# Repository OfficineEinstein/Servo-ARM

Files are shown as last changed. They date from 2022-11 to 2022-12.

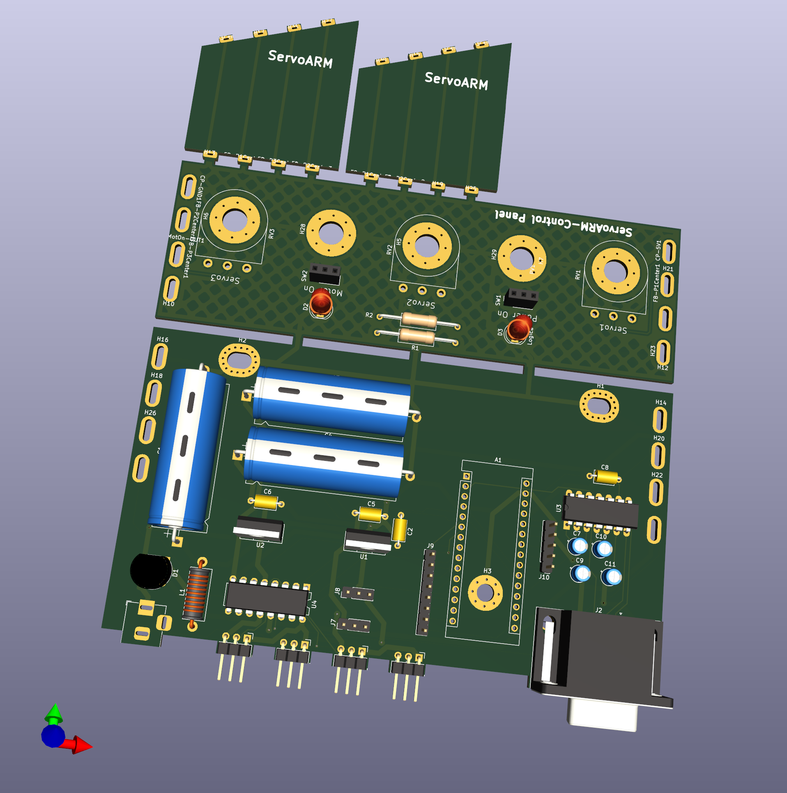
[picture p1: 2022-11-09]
ServoARM-r01/Kic/ServoARM-r01/ServoARM-r01.png

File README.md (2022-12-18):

# Servo-ARM
Tester Controller per servo analogici (Futaba)
## Descrizione di massima
Questo dispoositivo nasce per consentire l'agevole studio dei generatori PWM, delle loro funzionalità e del loro sfruttamento. Per praticità è stato individuato come controllore per servo meccanismi a tre fili di tipo Futaba ma, in effetti è utilizzabile per un'ampio spettro di esperienze che comprendono l'utilizzo di segnali PWM o comunque la generazione di onde quadre o treni di impulsi anche associati ad un'uscita di potenza.

Il dispositivo si basa su 
##### * un microcontrollore Atmel ATMEGA328P installato su una scheda Arduino Nano equivalente.
##### * tre potenziometri per la scelta dell'ampiezza dell'inpulso dei 3 generatori PWM.
##### * quattro uscite per servo controllate tramite quattro semi ponti H.
##### * un alimentatore con ingresso in corrente continua o alternata e due unità di uscita separate (logica e servo).
Il potenziometro numero 3 è collegato a due uscite così da poter controllare due servo in contemporanea.

# Hardware
## r00
La versione zero (quella di cui attualmente sono disponibili i PCB) presenta alcune criticità in fase di correzione nella versione r01

### Ponnte raddrizzatore
Il ponte previsto nel PCB ha una piedinatura inusuale per cui, se si usa un ponte standard si devono piegare ed incrociare i piedini in maniera da posizion arli correttamente

### Piedinatura di uscita
La piedinatura di uscita per i servo ha i piedini 2 e 3 invertiti (fa riferimento ad un tipo di servo diverso dallo standard Futaba)

## r01
Nella versione r01 attualmente in fase di perfezionamento tutti i problemi evidenziati nella versione r00 sono in fase di eliminazione. I PCB della versione saranno facilemente riconoscibili anche attraverso la dicitura PCB r01 riportata nelle serigrafie

# Software
Al momento non è stata rilasciata una versione di riferimento del codice per il funzionamento di questo strumento.

Si ricorda che se si adotta come microcontrollore la scheda Maker Nano, in fase di compilazione si dovrà scegliere la versione di bootloader più aggiornata diversamente verrà restituito un errore in fase di caricamento del codice.

Il dispositivo si basa sulla funzione PWM disponibile nella libreria di base di Arduino (analogWrite()).
Anche se in fase di sperimentazione è possibile utilizzare le librerie disponibili per il controllo dei servo, sarebbe opportuno controllare i generatori PWM direttamente ovvero tramite comandi analogWrite() e non tramite chiamate alle librerie per il controllo dei servo.

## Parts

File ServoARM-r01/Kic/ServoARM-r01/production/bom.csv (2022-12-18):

Designator | Footprint | Quantity | Value | LCSC Part #
A1 | Arduino_Nano | 1 | Arduino_Nano_v3.x
C1, C3, C4 | CP_Axial_L37.0mm_D13.0mm_P43.00mm_Horizontal | 3 | C_Polarized
C10, C11, C7, C9 | CP_Radial_D4.0mm_P2.00mm | 4 | 1uF
C2, C5, C6 | C_Axial_L5.1mm_D3.1mm_P7.50mm_Horizontal | 3 | C
C8 | C_Axial_L5.1mm_D3.1mm_P7.50mm_Horizontal | 1 | 100nF
CP-5V1, CP-GND1, FP-MotOn-OUT1, H10, H12, H14, H16, H18, H20, H21, H22, H23, H26 | Asola | 13 | MountingHole_Pad
D1 | Diode_Bridge_Round_D8.9mm | 1 | D_Bridge_+A-A
D2 | LED_D5.0mm | 1 | Motori
D3 | LED_D5.0mm | 1 | Logica
FB-P1Center1 | Asola | 1 | FB-P1Center
FB-P1Center2, FB-P1Center3 | TenonePerAsola | 2 | FB-P1Center
FB-P2Center1 | Asola | 1 | FB-P2Center
FB-P2Center2, FB-P2Center3 | TenonePerAsola | 2 | FB-P2Center
FB-P3Center1 | Asola | 1 | FB-P3Center
FB-P3Center3, FB-P3Center4, FB-P3Center5, FB-P3Center6 | TenonePerAsola | 4 | FB-P3Center
H1, H2 | MountingHole_4.3x6.2mm_M4_Pad_Via | 2 | MountingHole_Pad
H13, H15, H17, H19, H25, H27, H30, H31 | TenonePerAsola | 8 | MountingHole_Pad
H28, H29, H5, H6, H7 | MountingHole_6.5mm_Pad_Via | 5 | MountingHole_Pad
H3 | MountingHole_4.3mm_M4_Pad_Via | 1 | MountingHole_Pad
J1 | BarrelJack_Horizontal | 1 | Barrel_Jack_MountingPin
J10 | PinHeader_1x05_P2.54mm_Vertical | 1 | Conn_01x05
J2 | DSUB-9_Female_Horizontal_P2.77x2.84mm_EdgePinOffset14.56mm_Housed_MountingHolesOffset15.98mm | 1 | DB9_Female_MountingHoles
J3, J4, J5, J6 | PinHeader_1x03_P2.54mm_Horizontal | 4 | Conn_01x03
J7, J8 | PinHeader_1x03_P2.54mm_Vertical | 2 | Conn_01x03
J9 | PinHeader_1x08_P2.54mm_Vertical | 1 | Conn_01x08
L1 | L_Axial_L12.0mm_D5.0mm_P15.24mm_Horizontal_Fastron_MISC | 1 | L
R1, R2 | R_Axial_DIN0309_L9.0mm_D3.2mm_P20.32mm_Horizontal | 2 | R
RV1, RV2, RV3 | Potentiometer_Omeg_PC16BU_Vertical | 3 | R_Potentiometer
SW1 | PinSocket_1x03_P2.54mm_Vertical | 1 | SwGenerale
SW2 | PinSocket_1x03_P2.54mm_Vertical | 1 | SwMotori
U1, U2 | TO-220-3_Vertical | 2 | LM7805_TO220
U3 | DIP-14_W7.62mm_LongPads | 1 | MAX232
U4 | DIP-16_W7.62mm | 1 | SN754410NE

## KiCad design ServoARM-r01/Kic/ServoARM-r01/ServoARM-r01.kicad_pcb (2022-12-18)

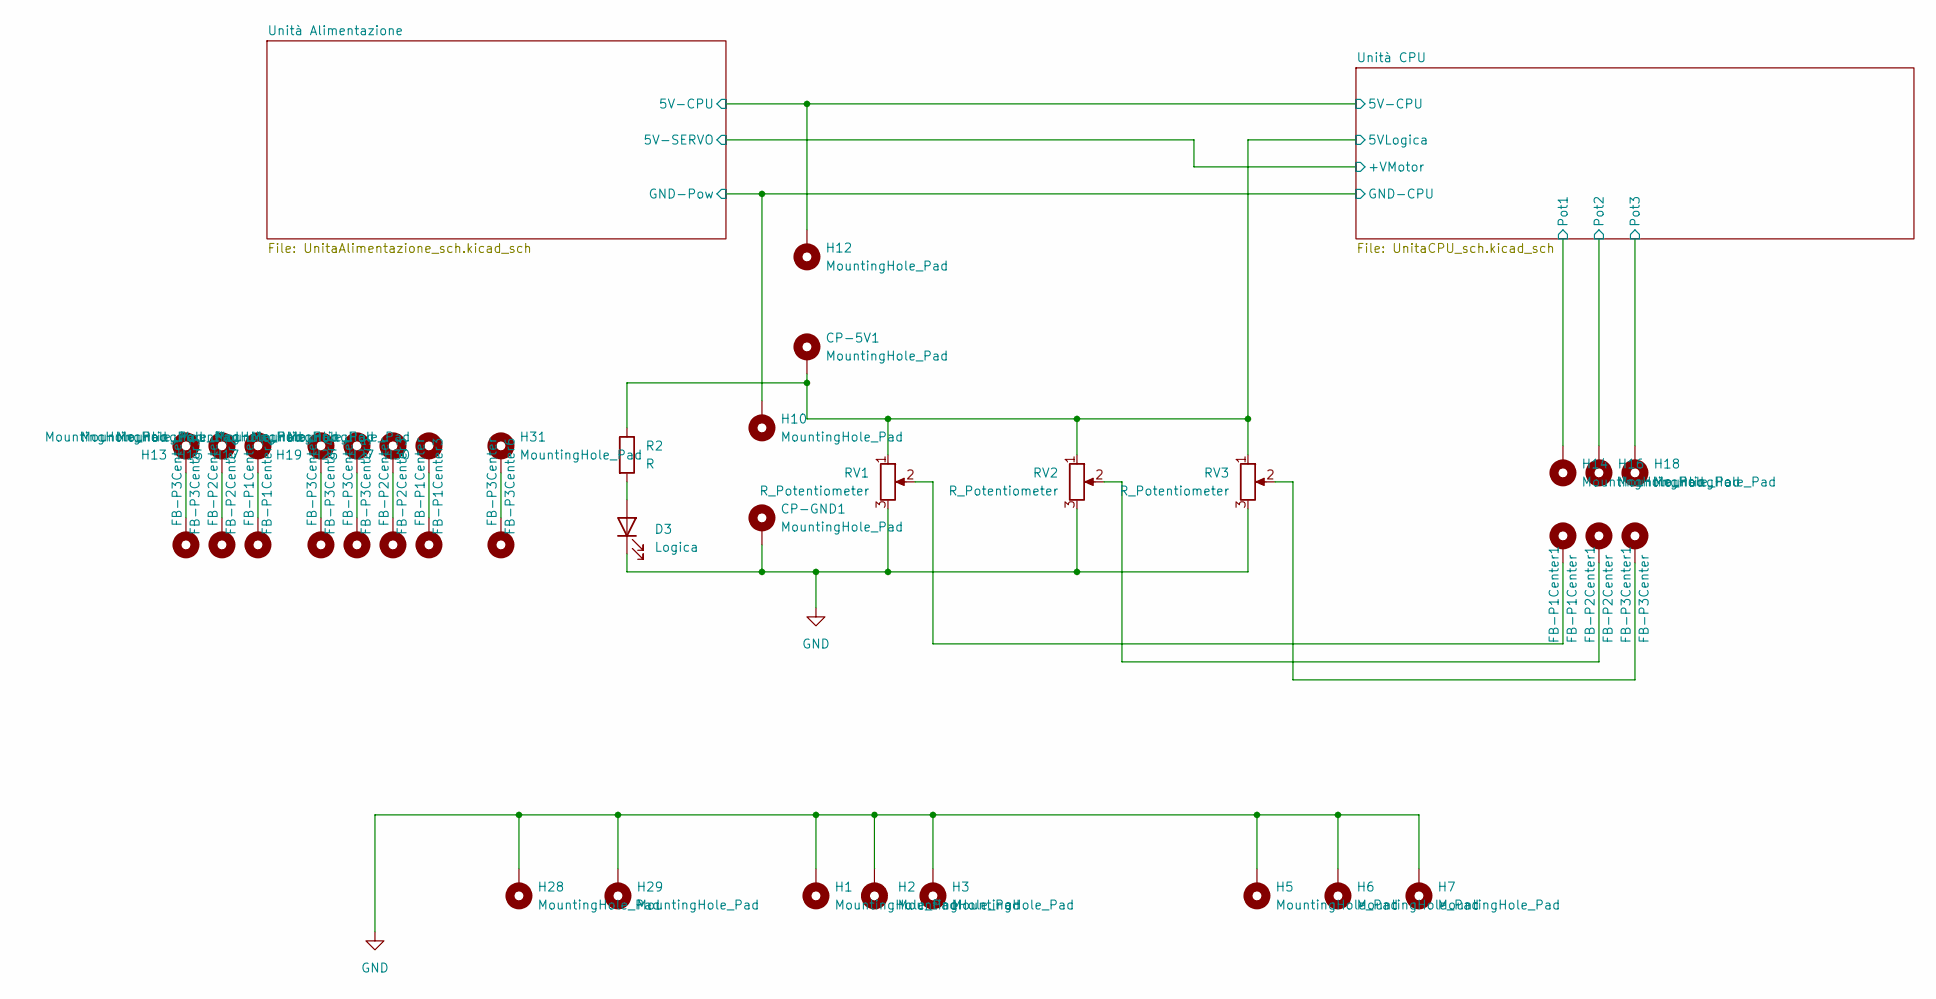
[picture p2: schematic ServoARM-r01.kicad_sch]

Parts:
CP-5V1: MountingHole_Pad; Asola
CP-GND1: MountingHole_Pad; Asola
D3: Logica; LED_D5.0mm
FB-P1Center1: FB-P1Center; Asola
FB-P1Center2, FB-P1Center3: FB-P1Center; TenonePerAsola
FB-P2Center1: FB-P2Center; Asola
FB-P2Center2, FB-P2Center3: FB-P2Center; TenonePerAsola
FB-P3Center1: FB-P3Center; Asola
FB-P3Center3, FB-P3Center4, FB-P3Center5, FB-P3Center6: FB-P3Center; TenonePerAsola
H1, H2: MountingHole_Pad; MountingHole_4.3x6.2mm_M4_Pad_Via
H3: MountingHole_Pad; MountingHole_4.3mm_M4_Pad_Via
H5, H6, H7, H28, H29: MountingHole_Pad; MountingHole_6.5mm_Pad_Via
H10, H12, H14, H16, H18: MountingHole_Pad; Asola
H13, H15, H17, H19, H25, H27, H30, H31: MountingHole_Pad; TenonePerAsola
R2: R; R_Axial_DIN0309_L9.0mm_D3.2mm_P20.32mm_Horizontal
RV1, RV2, RV3: R_Potentiometer; Potentiometer_Omeg_PC16BU_Vertical

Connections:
/Unità CPU/5VLogica: CP-5V1.1, R2.1, RV1.1, RV2.1, RV3.1; also elsewhere on the board
/Unità CPU/Pot1: H14.1; also elsewhere on the board
/Unità CPU/Pot2: H16.1; also elsewhere on the board
/Unità CPU/Pot3: H18.1; also elsewhere on the board
GND: CP-GND1.1, D3.1 (K), H1.1, H2.1, H3.1, H5.1, H6.1, H7.1, H10.1, H28.1, H29.1, RV1.3, RV2.3, RV3.3; also elsewhere on the board
unnamed: D3.2 (A), R2.2
unnamed: FB-P1Center1.1, RV1.2
unnamed: FB-P1Center2.1, H17.1
unnamed: FB-P1Center3.1, H30.1
unnamed: FB-P2Center1.1, RV2.2
unnamed: FB-P2Center2.1, H15.1
unnamed: FB-P2Center3.1, H27.1
unnamed: FB-P3Center1.1, RV3.2
unnamed: FB-P3Center3.1, H13.1
unnamed: FB-P3Center4.1, H19.1
unnamed: FB-P3Center5.1, H25.1
unnamed: FB-P3Center6.1, H31.1

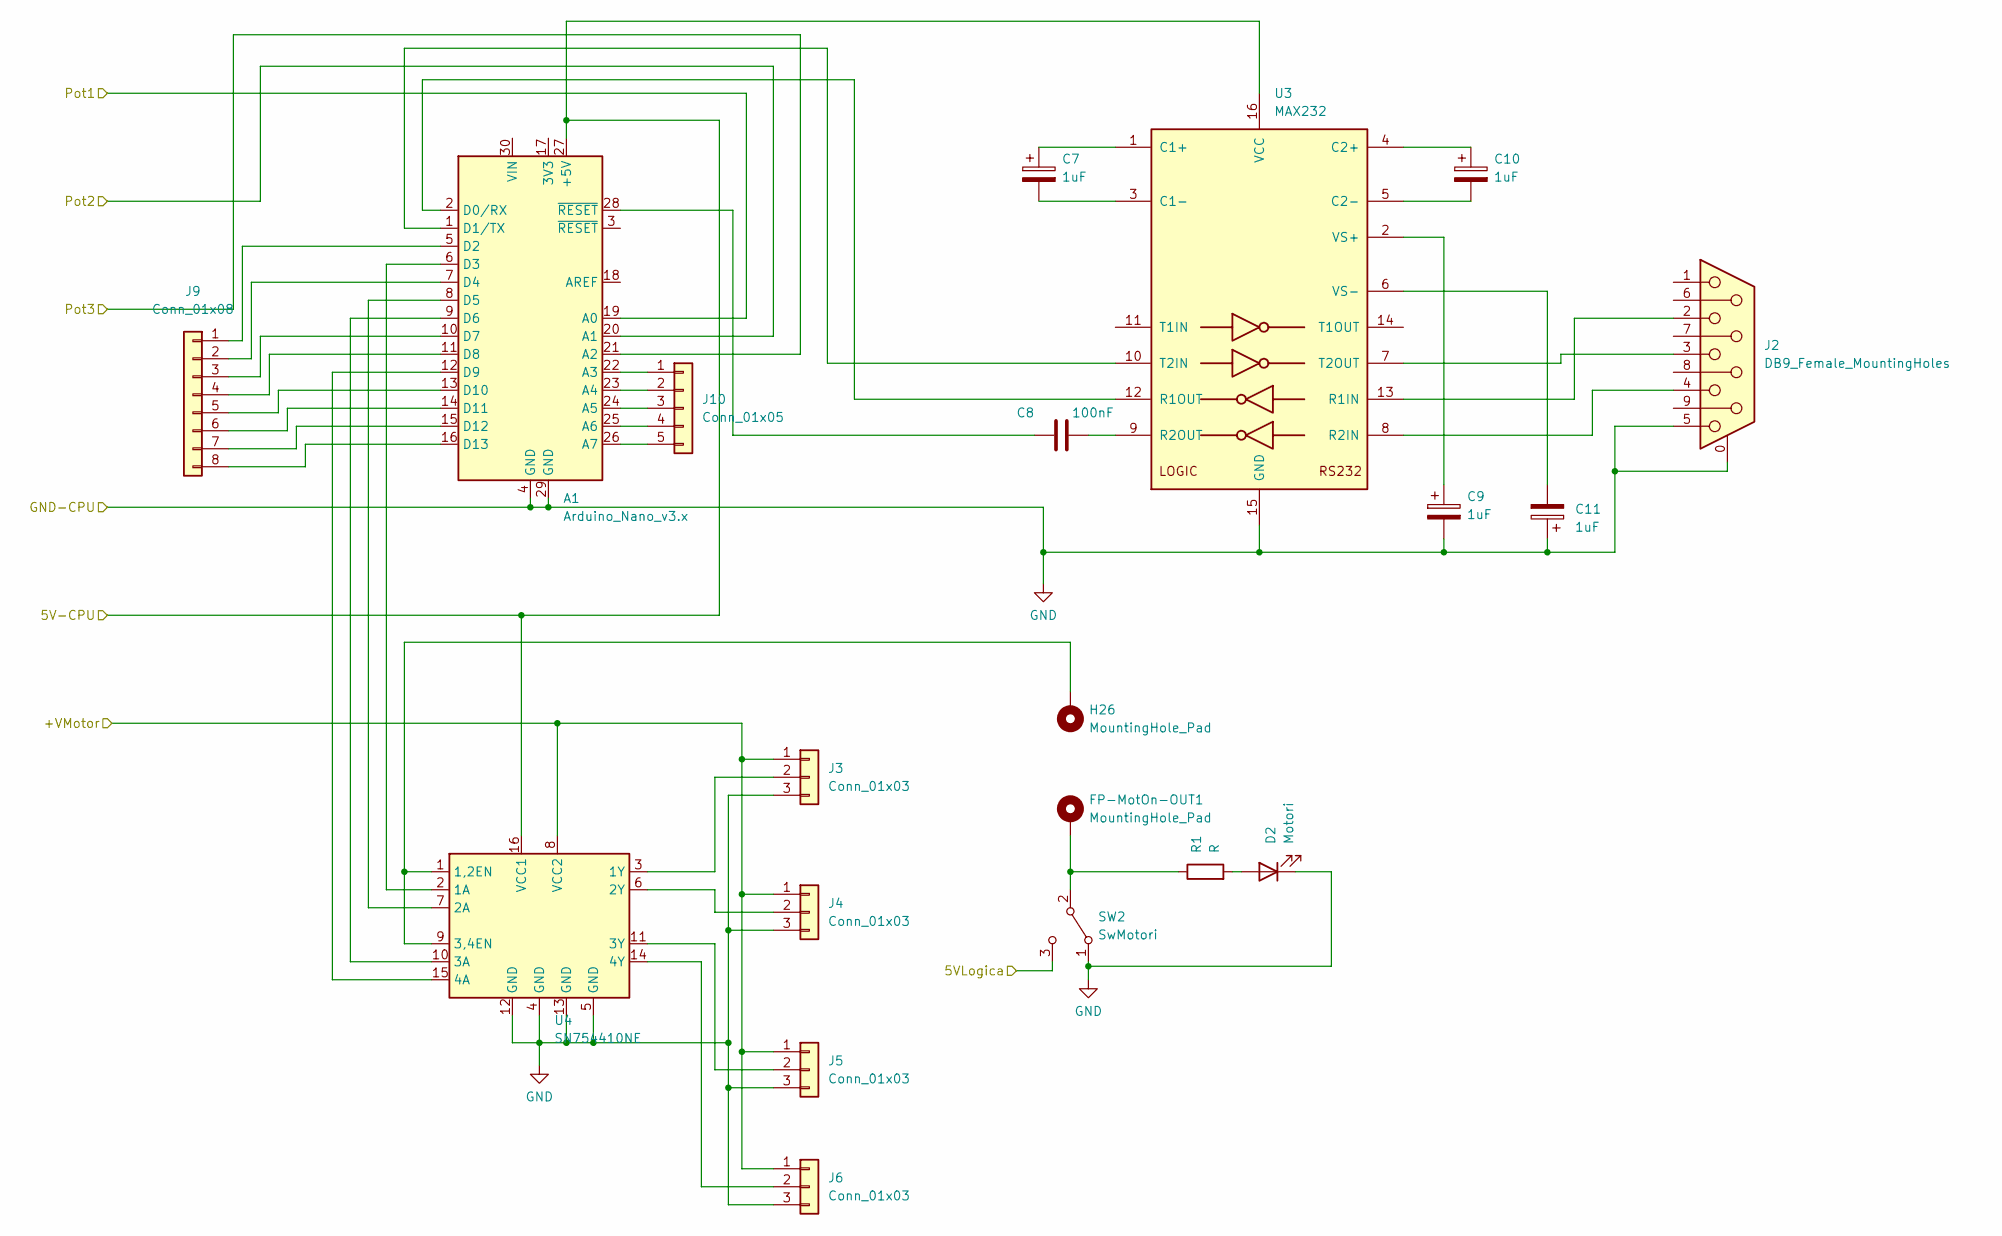
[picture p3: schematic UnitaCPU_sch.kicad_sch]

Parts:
A1: Arduino_Nano_v3.x; Arduino_Nano
C7, C9, C10, C11: 1uF; CP_Radial_D4.0mm_P2.00mm
C8: 100nF; C_Axial_L5.1mm_D3.1mm_P7.50mm_Horizontal
D2: Motori; LED_D5.0mm
FP-MotOn-OUT1: MountingHole_Pad; Asola
H26: MountingHole_Pad; Asola
J2: DB9_Female_MountingHoles; DSUB-9_Female_Horizontal_P2.77x2.84mm_EdgePinOffset14.56mm_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
J3, J4, J5, J6: Conn_01x03; PinHeader_1x03_P2.54mm_Horizontal
J9: Conn_01x08; PinHeader_1x08_P2.54mm_Vertical
J10: Conn_01x05; PinHeader_1x05_P2.54mm_Vertical
R1: R; R_Axial_DIN0309_L9.0mm_D3.2mm_P20.32mm_Horizontal
SW2: SwMotori; PinSocket_1x03_P2.54mm_Vertical
U3: MAX232; DIP-14_W7.62mm_LongPads
U4: SN754410NE; DIP-16_W7.62mm

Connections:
/Unità CPU/5VLogica: SW2.3 (C); also elsewhere on the board
/Unità CPU/Pot1: A1.19 (A0); also elsewhere on the board
/Unità CPU/Pot2: A1.20 (A1); also elsewhere on the board
/Unità CPU/Pot3: A1.21 (A2); also elsewhere on the board
GND: A1.4 (GND), A1.29 (GND), C9.2, C11.1, D2.1 (K), J2.0 (PAD), J2.5, J3.3, J4.3, J5.3, J6.3, SW2.1 (A), U3.15 (GND), U4.4 (GND), U4.5 (GND), U4.12 (GND), U4.13 (GND); also elsewhere on the board
unnamed: A1.1 (D1/TX), U3.10 (T2IN)
unnamed: A1.2 (D0/RX), U3.12 (R1OUT)
unnamed: A1.5 (D2), J9.1
unnamed: A1.6 (D3), U4.2 (1A)
unnamed: A1.7 (D4), J9.2
unnamed: A1.8 (D5), U4.7 (2A)
unnamed: A1.9 (D6), U4.10 (3A)
unnamed: A1.10 (D7), J9.3
unnamed: A1.11 (D8), J9.4
unnamed: A1.12 (D9), U4.15 (4A)
unnamed: A1.13 (D10), J9.5
unnamed: A1.14 (D11), J9.6
unnamed: A1.15 (D12), J9.7
unnamed: A1.16 (D13), J9.8
unnamed: A1.22 (A3), J10.1
unnamed: A1.23 (A4), J10.2
unnamed: A1.24 (A5), J10.3
unnamed: A1.25 (A6), J10.4
unnamed: A1.26 (A7), J10.5
unnamed: A1.28 (~RESET), C8.1
unnamed: C7.1, U3.1 (C1+)
unnamed: C7.2, U3.3 (C1-)
unnamed: C8.2, U3.9 (R2OUT)
unnamed: C9.1, U3.2 (VS+)
unnamed: C10.1, U3.4 (C2+)
unnamed: C10.2, U3.5 (C2-)
unnamed: C11.2, U3.6 (VS-)
unnamed: D2.2 (A), R1.2
unnamed: FP-MotOn-OUT1.1, R1.1, SW2.2 (B)
unnamed: H26.1, U4.1 (1,2EN), U4.9 (3,4EN)
unnamed: J2.2, U3.13 (R1IN)
unnamed: J2.3, U3.7 (T2OUT)
unnamed: J2.4, U3.8 (R2IN)
unnamed: J3.2, U4.3 (1Y)
unnamed: J4.2, U4.6 (2Y)
unnamed: J5.2, U4.11 (3Y)
unnamed: J6.2, U4.14 (4Y)

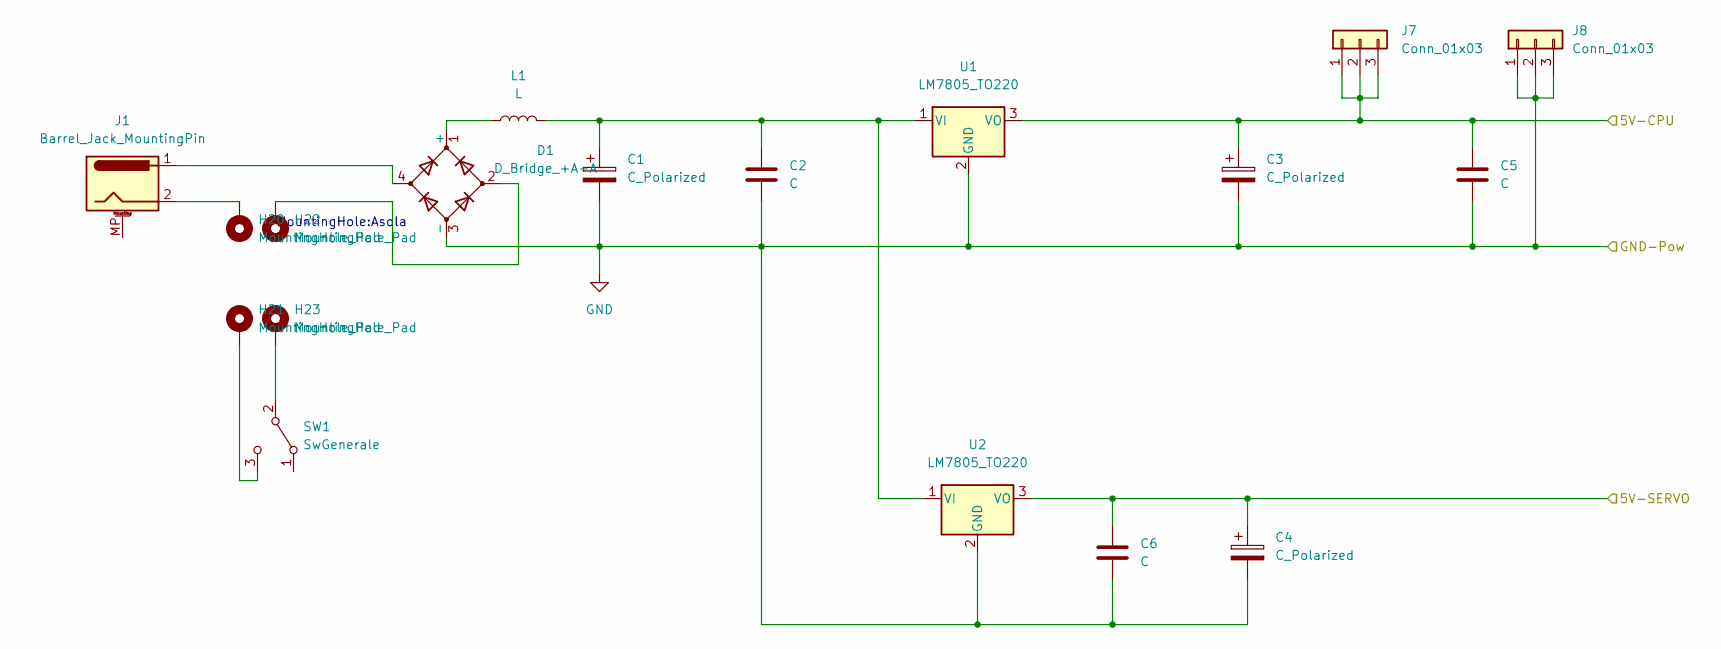
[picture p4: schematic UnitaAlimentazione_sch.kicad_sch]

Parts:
C1, C3, C4: C_Polarized; CP_Axial_L37.0mm_D13.0mm_P43.00mm_Horizontal
C2, C5, C6: C; C_Axial_L5.1mm_D3.1mm_P7.50mm_Horizontal
D1: D_Bridge_+A-A; Diode_Bridge_Round_D8.9mm
H20, H21, H22, H23: MountingHole_Pad; Asola
J1: Barrel_Jack_MountingPin; BarrelJack_Horizontal
J7, J8: Conn_01x03; PinHeader_1x03_P2.54mm_Vertical
L1: L; L_Axial_L12.0mm_D5.0mm_P15.24mm_Horizontal_Fastron_MISC
SW1: SwGenerale; PinSocket_1x03_P2.54mm_Vertical
U1, U2: LM7805_TO220; TO-220-3_Vertical

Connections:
GND: C1.2, C2.2, C3.2, C4.2, C5.2, C6.2, D1.3 (-), J8.1, J8.2, J8.3, U1.2 (GND), U2.2 (GND); also elsewhere on the board
unnamed: C1.1, C2.1, L1.2, U1.1 (VI), U2.1 (VI)
unnamed: D1.1 (+), L1.1
unnamed: D1.4, J1.1
unnamed: H20.1, J1.2
unnamed: H21.1, SW1.3 (C)
unnamed: D1.2, H22.1
unnamed: H23.1, SW1.2 (B)

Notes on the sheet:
MountingHole:Asola

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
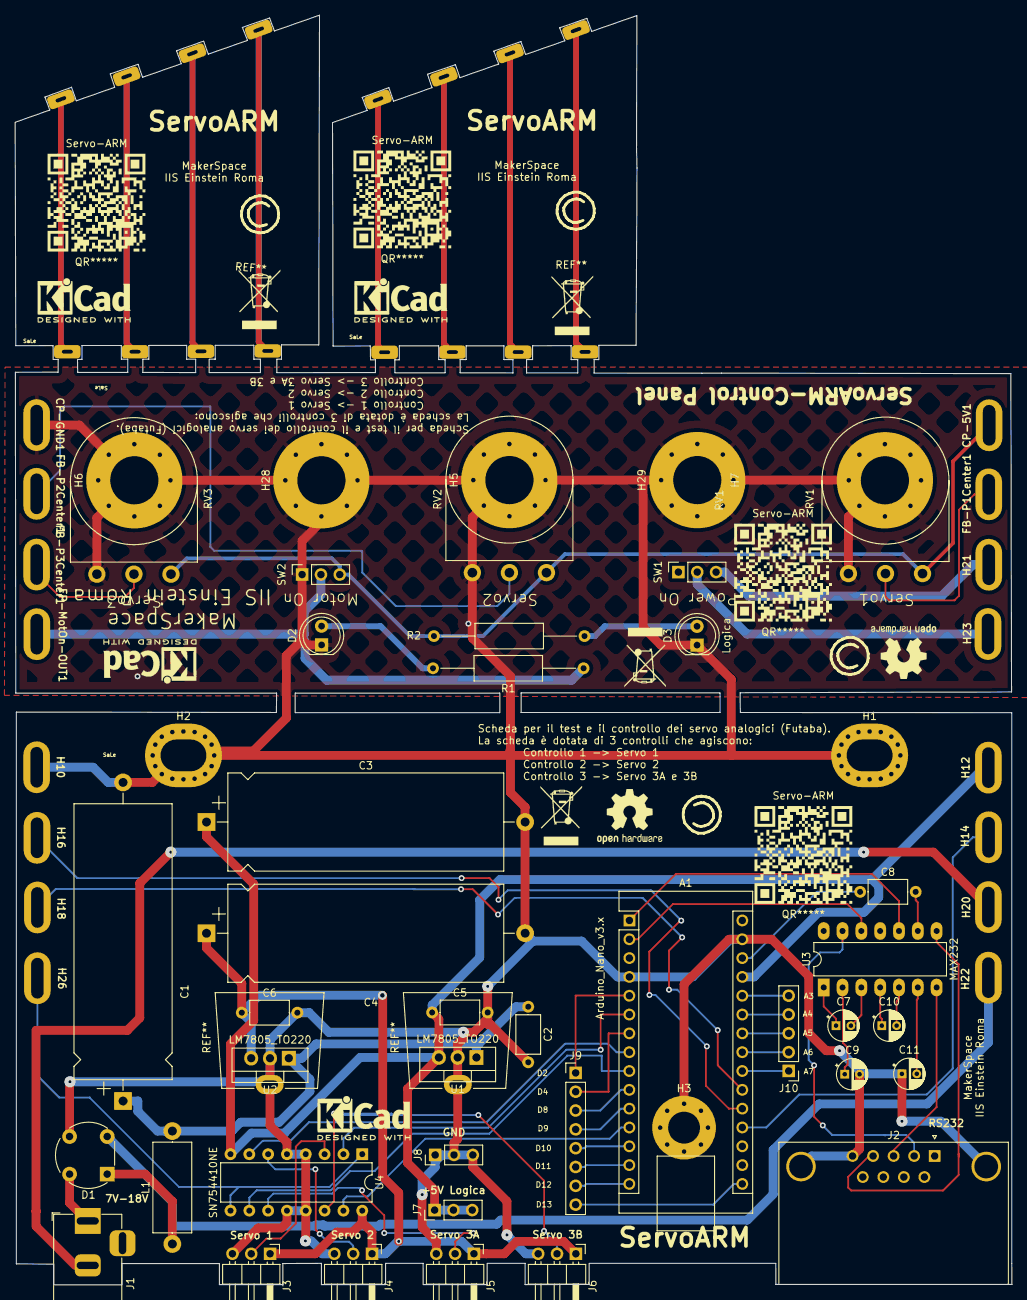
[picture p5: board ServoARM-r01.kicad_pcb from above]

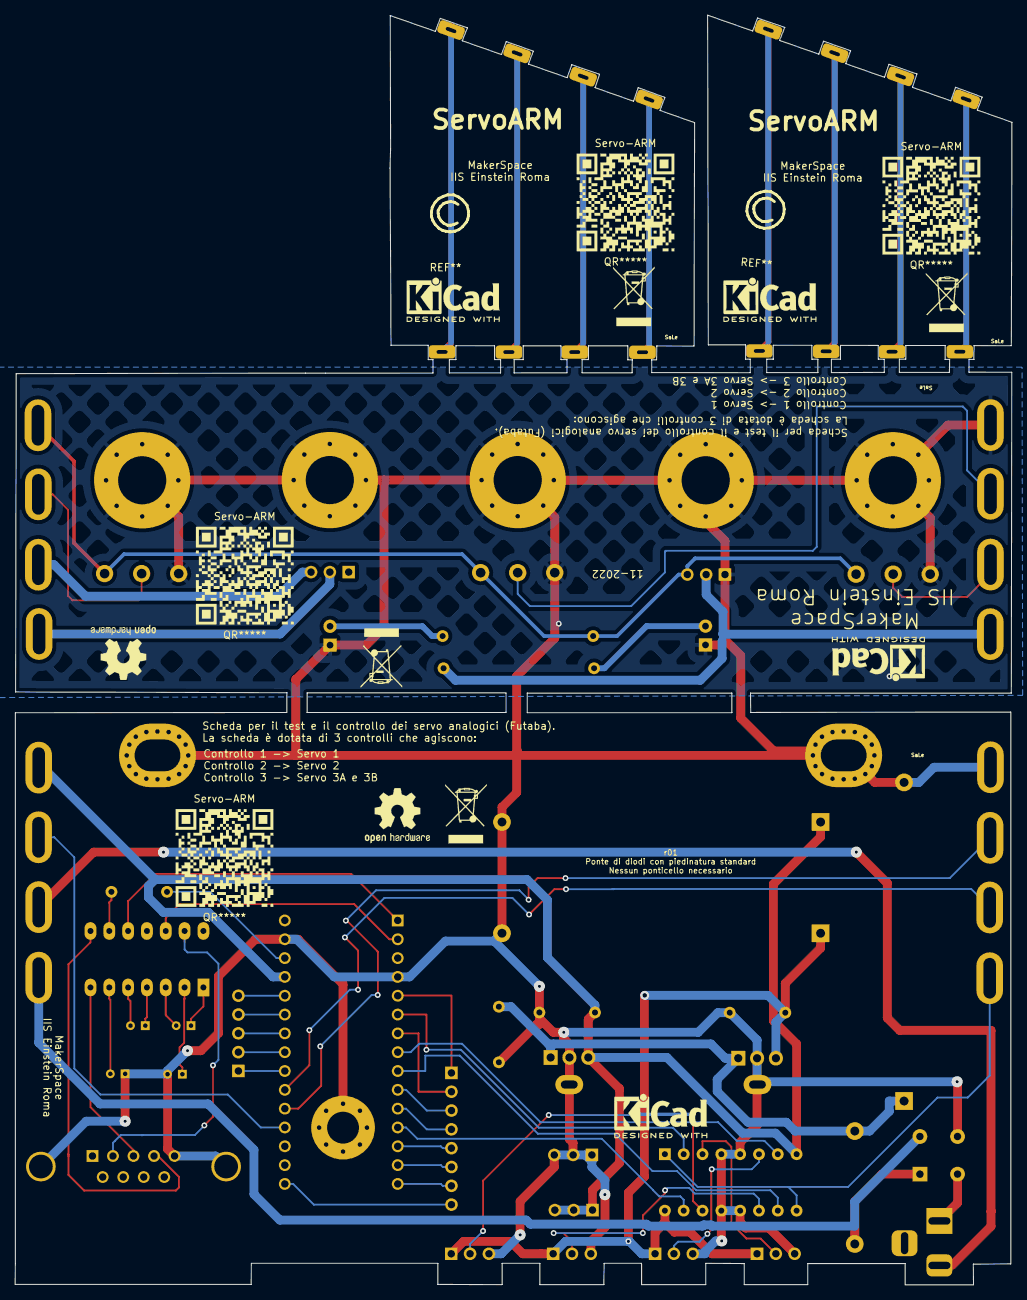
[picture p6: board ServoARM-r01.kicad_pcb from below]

Board: 2 copper layers, 134.5 x 171.3 mm, 85 parts (4 on the bottom side), 63 nets.

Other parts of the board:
QR*****: Servo-ARM
QR*****#2, QR*****#3, QR*****#4, QR*****#5, QR*****#6, QR*****#7, QR*****#8: Servo-ARM

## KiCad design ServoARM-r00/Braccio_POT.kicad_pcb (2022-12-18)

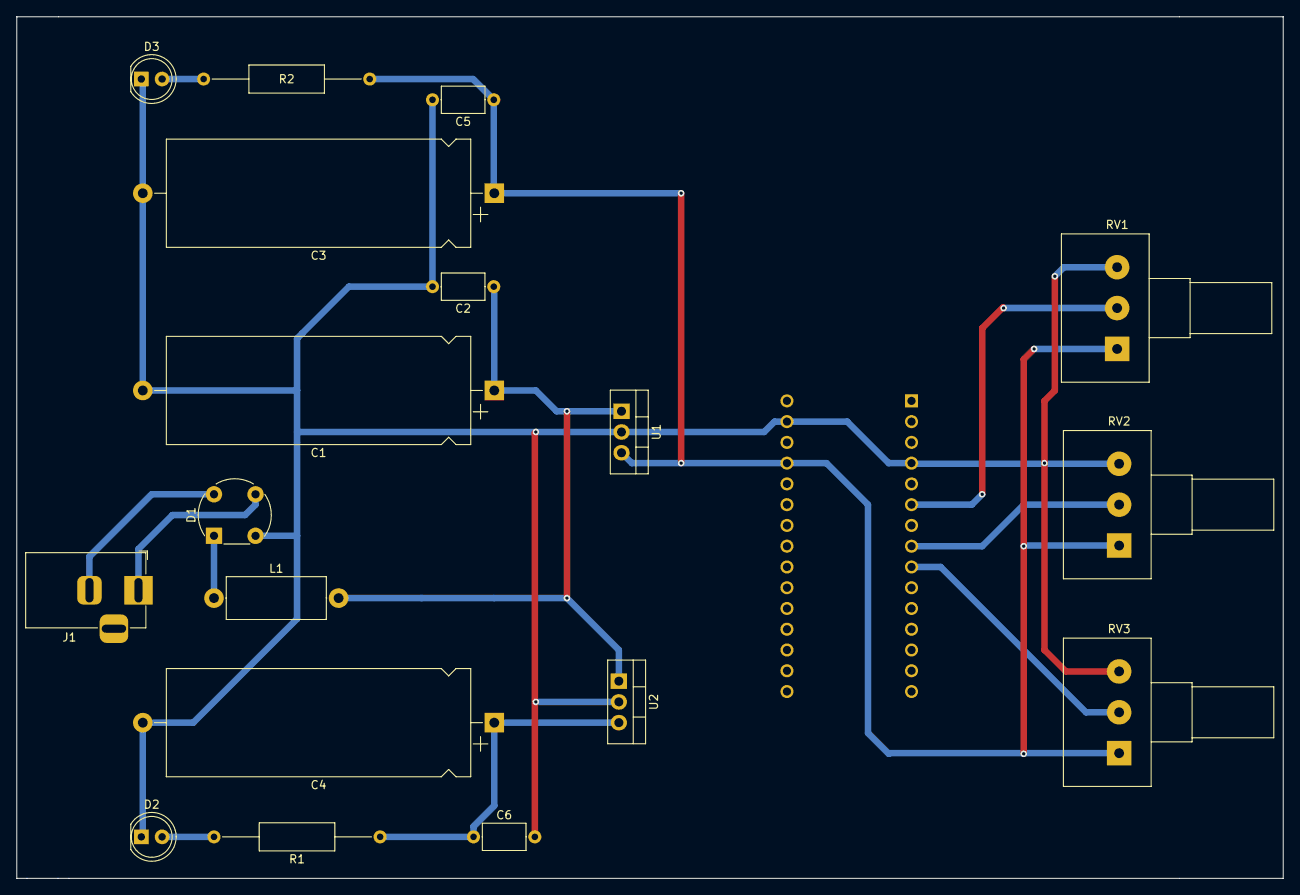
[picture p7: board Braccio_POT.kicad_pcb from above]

Board: 2 copper layers, 154.9 x 105.4 mm, 19 parts (1 on the bottom side), 12 nets.

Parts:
A1: Arduino_Nano_v3.x; Arduino_Nano
C1, C3, C4: C_Polarized; CP_Axial_L37.0mm_D13.0mm_P43.00mm_Horizontal
C2, C5, C6: C; C_Axial_L5.1mm_D3.1mm_P7.50mm_Horizontal
D1: D_Bridge_+-AA; Diode_Bridge_Round_D8.9mm
D2: LED Verde; LED_D5.0mm
D3: LED Rosso; LED_D5.0mm
J1: Barrel_Jack_MountingPin; BarrelJack_Horizontal
L1: L; L_Axial_L12.0mm_D5.0mm_P15.24mm_Horizontal_Fastron_MISC
R1, R2: R; R_Axial_DIN0309_L9.0mm_D3.2mm_P20.32mm_Horizontal
RV1, RV2, RV3: R_Potentiometer; Potentiometer_Alps_RK163_Single_Horizontal
U1, U2: LM7805_TO220; TO-220-3_Vertical

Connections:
/Unità Alimentazione/5V-CPU: A1.27 (+5V), C3.1, C5.1, R2.1, RV1.1, RV2.1, RV3.1, U1.3 (VO)
/Unità Alimentazione/5V-SERVO: C4.1, C6.1, R1.1, U2.3 (VO)
/Unità Alimentazione/GND-Pow: A1.4 (GND), A1.29 (GND), C1.2, C2.2, C3.2, C4.2, C5.2, C6.2, D1.2 (-), D2.1 (K), D3.1 (K), RV1.3, RV2.3, RV3.3, U1.2 (GND), U2.2 (GND)
/Unità CPU/Pot1: A1.6 (D3), RV1.2
/Unità CPU/Pot2: A1.8 (D5), RV2.2
/Unità CPU/Pot3: A1.9 (D6), RV3.2
unnamed: C1.1, C2.1, L1.2, U1.1 (VI), U2.1 (VI)
unnamed: D1.1 (+), L1.1
unnamed: D1.3, J1.1
unnamed: D1.4, J1.2
unnamed: D2.2 (A), R1.2
unnamed: D3.2 (A), R2.2

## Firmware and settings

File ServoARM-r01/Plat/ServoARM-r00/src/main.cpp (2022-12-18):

#include <Arduino.h>

//Gestione Potenziometri
#define NumPot 3
#define Pot1 0
#define Pot2 1
#define Pot3 2

uint8_t Pot[NumPot] = {Pot1, Pot2, Pot3};
uint16_t ARead[NumPot];

//Gestone ADC
#define ADCStep 1023

//Gestione PWM
#define PWMStep 255
#define NumPWMPort 4
#define PWMOut1 3
#define PWMOut2 5
#define PWMOut3 6
#define PWMOut4 9

uint8_t PWMOut[NumPWMPort] = {PWMOut1, PWMOut2, PWMOut3, PWMOut4};
uint16_t PWMVal[NumPWMPort];

void setup() 
{
  Serial.begin(115200);
  Serial.println("Prova Microfono");
}

void loop() 
{
  Serial.print("Potenziometro ");
  for (uint8_t ii=0; ii<NumPot; ii++)
  {
    Serial.print(ii+1);
    Serial.print(" -> ");
    //legge i singoli potenziometri (0-1023),
    //Carica il risultato nell'array ARead[] per successive elaborazioni
    ARead[ii] = analogRead(Pot[ii]);
    //Riproietta il valore letto dalla scala dell'ADC alla scala del PWM
    //e salva il valore per successive elaborazioni
    PWMVal[ii] = map(ARead[ii], 0, ADCStep, 0, PWMStep);
    Serial.print(PWMVal[ii]);
    Serial.print(" -");
    //Setta l'uscita corrispondente al potenziometro corrente
    //con il valore del PWM calcolato
    analogWrite(PWMOut[ii],PWMVal[ii]);
    //Se è il terzo potenziometro setta la quarta uscita allo stesso valore
    if (ii==2)
    {
      ii++;
      analogWrite(PWMOut[ii],PWMVal[ii-1]);
    }
  }
  Serial.println();
  delay(20);
}
